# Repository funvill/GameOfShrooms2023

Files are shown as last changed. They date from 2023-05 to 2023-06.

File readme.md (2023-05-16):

Working on [Idea 006 Procedurally Generated Glowing Mushroom Pcb](https://blog.abluestar.com/idea006-procedurally-generated-glowing-mushroom-pcb/) Using [p5js](https://p5js.org/) to generate the mushroom and [svg2shenzhen](https://github.com/badgeek/svg2shenzhen) to convert the SVG to KiCad.

For [Game of Shroom 2023](https://yumfactory.com/gameofshrooms/)

## Build

1. Open `p5js/index.html` in a browser
2. Right click and inspect the image, find the svg, copy the element, past the svg text into a new text document, save it as `output.svg`
3. Install [svg2shenzhen](https://github.com/badgeek/svg2shenzhen)
4. Open `output.svg` in inkscape.
5. Extention->svg2shenzhen->`1. Prep Document...`
6. Resize the image to fit within the page.
7. Copy red outline to the `edge.cuts` layer
8. Copy the black body to the `f.Cu` layer
9. Extention->svg2shenzhen->`2. Export to KiCad`

## Example

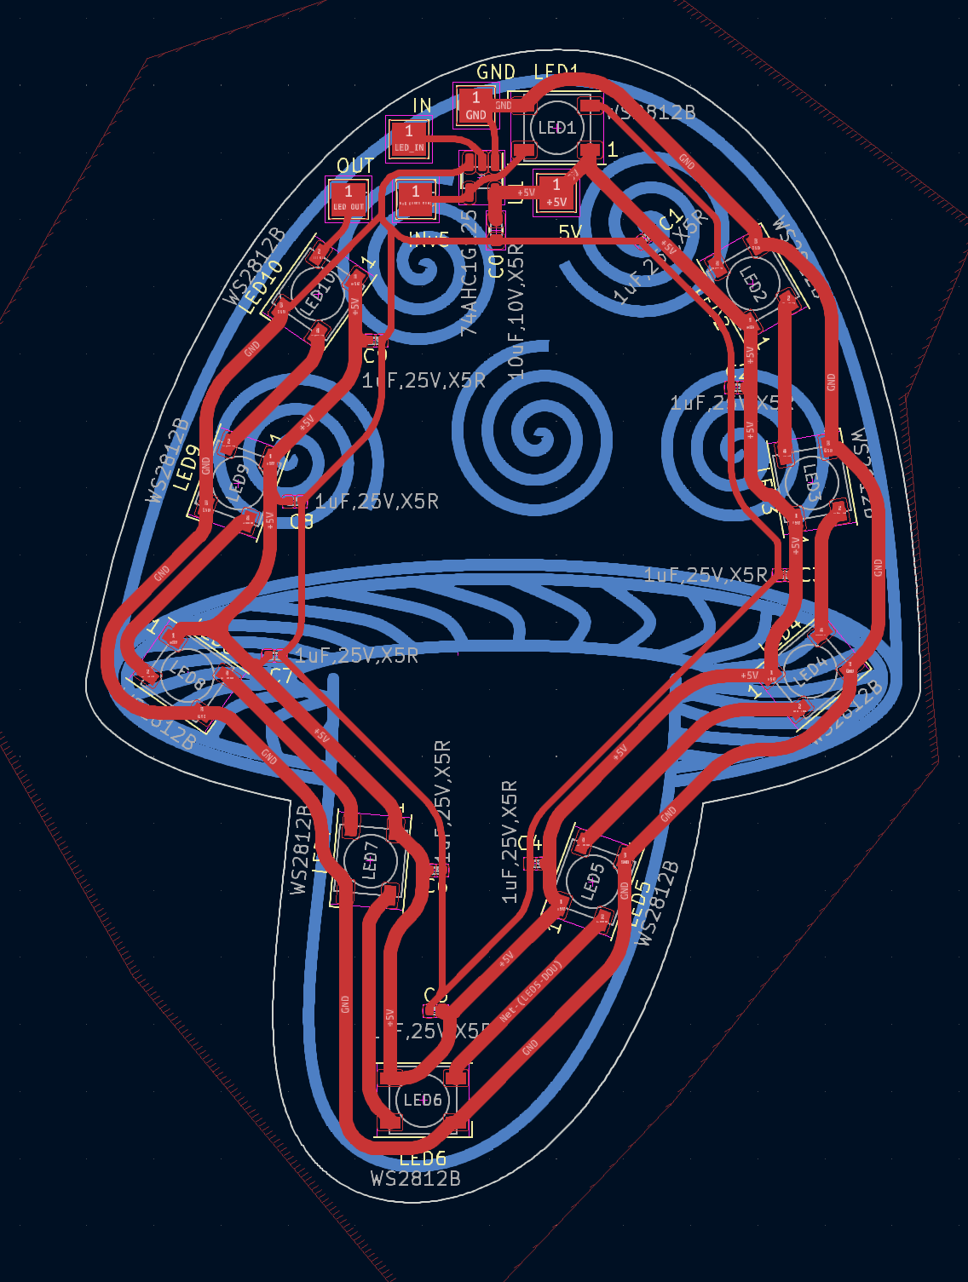
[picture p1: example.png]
Example


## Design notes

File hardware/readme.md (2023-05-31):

Based on this design
https://github.com/adafruit/Adafruit-QT-Py-ESP32-S2-PCB/tree/main

## BOM

- CPU (C529594) ESP32-S2 https://jlcpcb.com/partdetail/EspressifSystems-ESP32S2/C529594
- LED (C2843785) WS2812B XL-5050RGBC-WS2812B https://jlcpcb.com/partdetail/Xinglight-XL_5050RGBCWS2812B/C2843785
- Antenna (C89334) https://jlcpcb.com/partdetail/JohansonDielectrics-2450AT18A100E/C89334
- Linear Voltage Regulators (LDO) (C51118) https://jlcpcb.com/partdetail/DiodesIncorporated-AP2112K_33TRG1/C51118

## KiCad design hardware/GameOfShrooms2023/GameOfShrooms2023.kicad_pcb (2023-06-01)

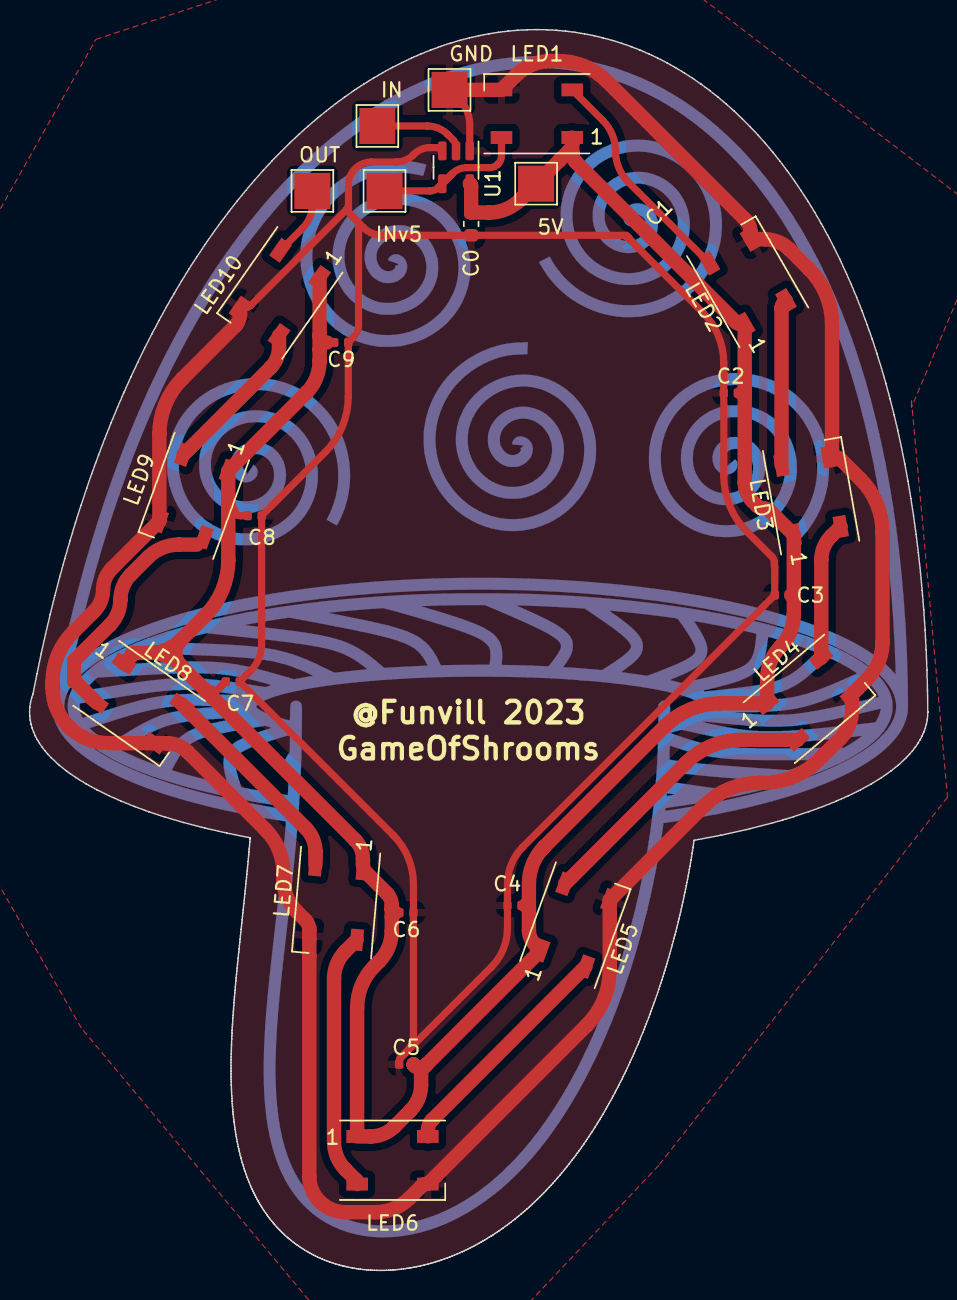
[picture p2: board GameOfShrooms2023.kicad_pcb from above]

Board: 2 copper layers, 62.2 x 86.0 mm, 26 parts (0 on the bottom side), 14 nets.

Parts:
5V: TestPoint; TestPoint_Pad_2.5x2.5mm
C0: 10uF,10V,X5R; C_0603_1608Metric
C1, C2, C3, C4, C5, C6, C7, C8, C9: 1uF,25V,X5R; C_0402_1005Metric
GND: TestPoint; TestPoint_Pad_2.5x2.5mm
IN: TestPoint; TestPoint_Pad_2.5x2.5mm
INv5: TestPoint; TestPoint_Pad_2.5x2.5mm
LED1, LED2, LED3, LED4, LED5, LED6, LED7, LED8, LED9, LED10: WS2812B; LED_WS2812B_PLCC4_5.0x5.0mm_P3.2mm
OUT: TestPoint; TestPoint_Pad_2.5x2.5mm
U1: 74AHC1G125; SOT-23-5

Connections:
+5V: 5V.1, C0.1, C1.2, C2.2, C3.2, C4.2, C5.2, C6.2, C7.2, C8.2, C9.2, LED1.1 (VDD), LED2.1 (VDD), LED3.1 (VDD), LED4.1 (VDD), LED5.1 (VDD), LED6.1 (VDD), LED7.1 (VDD), LED8.1 (VDD), LED9.1 (VDD), LED10.1 (VDD), U1.5 (VCC)
GND: C0.2, C1.1, C2.1, C3.1, C4.1, C5.1, C6.1, C7.1, C8.1, C9.1, GND.1, LED1.3 (GND), LED2.3 (GND), LED3.3 (GND), LED4.3 (GND), LED5.3 (GND), LED6.3 (GND), LED7.3 (GND), LED8.3 (GND), LED9.3 (GND), LED10.3 (GND), U1.1, U1.3 (GND)
LED_IN: IN.1, U1.2
LED_OUT: LED10.2 (DOU), OUT.1
unnamed: INv5.1, LED1.4 (DIN), U1.4
unnamed: LED1.2 (DOU), LED2.4 (DIN)
unnamed: LED2.2 (DOU), LED3.4 (DIN)
unnamed: LED3.2 (DOU), LED4.4 (DIN)
unnamed: LED4.2 (DOU), LED5.4 (DIN)
unnamed: LED5.2 (DOU), LED6.4 (DIN)
unnamed: LED6.2 (DOU), LED7.4 (DIN)
unnamed: LED7.2 (DOU), LED8.4 (DIN)
unnamed: LED8.2 (DOU), LED9.4 (DIN)
unnamed: LED9.2 (DOU), LED10.4 (DIN)

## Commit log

2023-05-16 working toolchain
    [drawing.kicad_pcb, output.kicad_pcb]
2023-05-31 Initial version of the PCB
    [GameOfShrooms2023.kicad_pcb, GameOfShrooms2023.kicad_sch, drawing.kicad_pcb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]
2023-06-01 Exported Gerbers
    [GameOfShrooms2023-B_Courtyard.gbr, GameOfShrooms2023-B_Cu.gbr, GameOfShrooms2023-B_Mask.gbr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]
